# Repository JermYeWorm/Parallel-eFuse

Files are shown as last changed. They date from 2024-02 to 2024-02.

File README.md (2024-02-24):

# Parallel eFuse Development Board
Parallel eFuse Dev Board for Robotics @ Maryland. Paralleled TPS25982 15A eFuse protection board designed to protect against current transients of up to 30A from RoboSub's electronic speed controllers. Built with KiCad 7.0.
<br><br>

## Design Visuals

<br>_Fig 1. Schematic Capture_<br><br>

Parallel_eFuse_2D
<br>_Fig 2. 2D PCB Layout_<br><br>


<br>_Fig 3. 3D Model (no components)_<br><br>


<br>_Fig 4. 3D Model (mounted components)_<br><br>

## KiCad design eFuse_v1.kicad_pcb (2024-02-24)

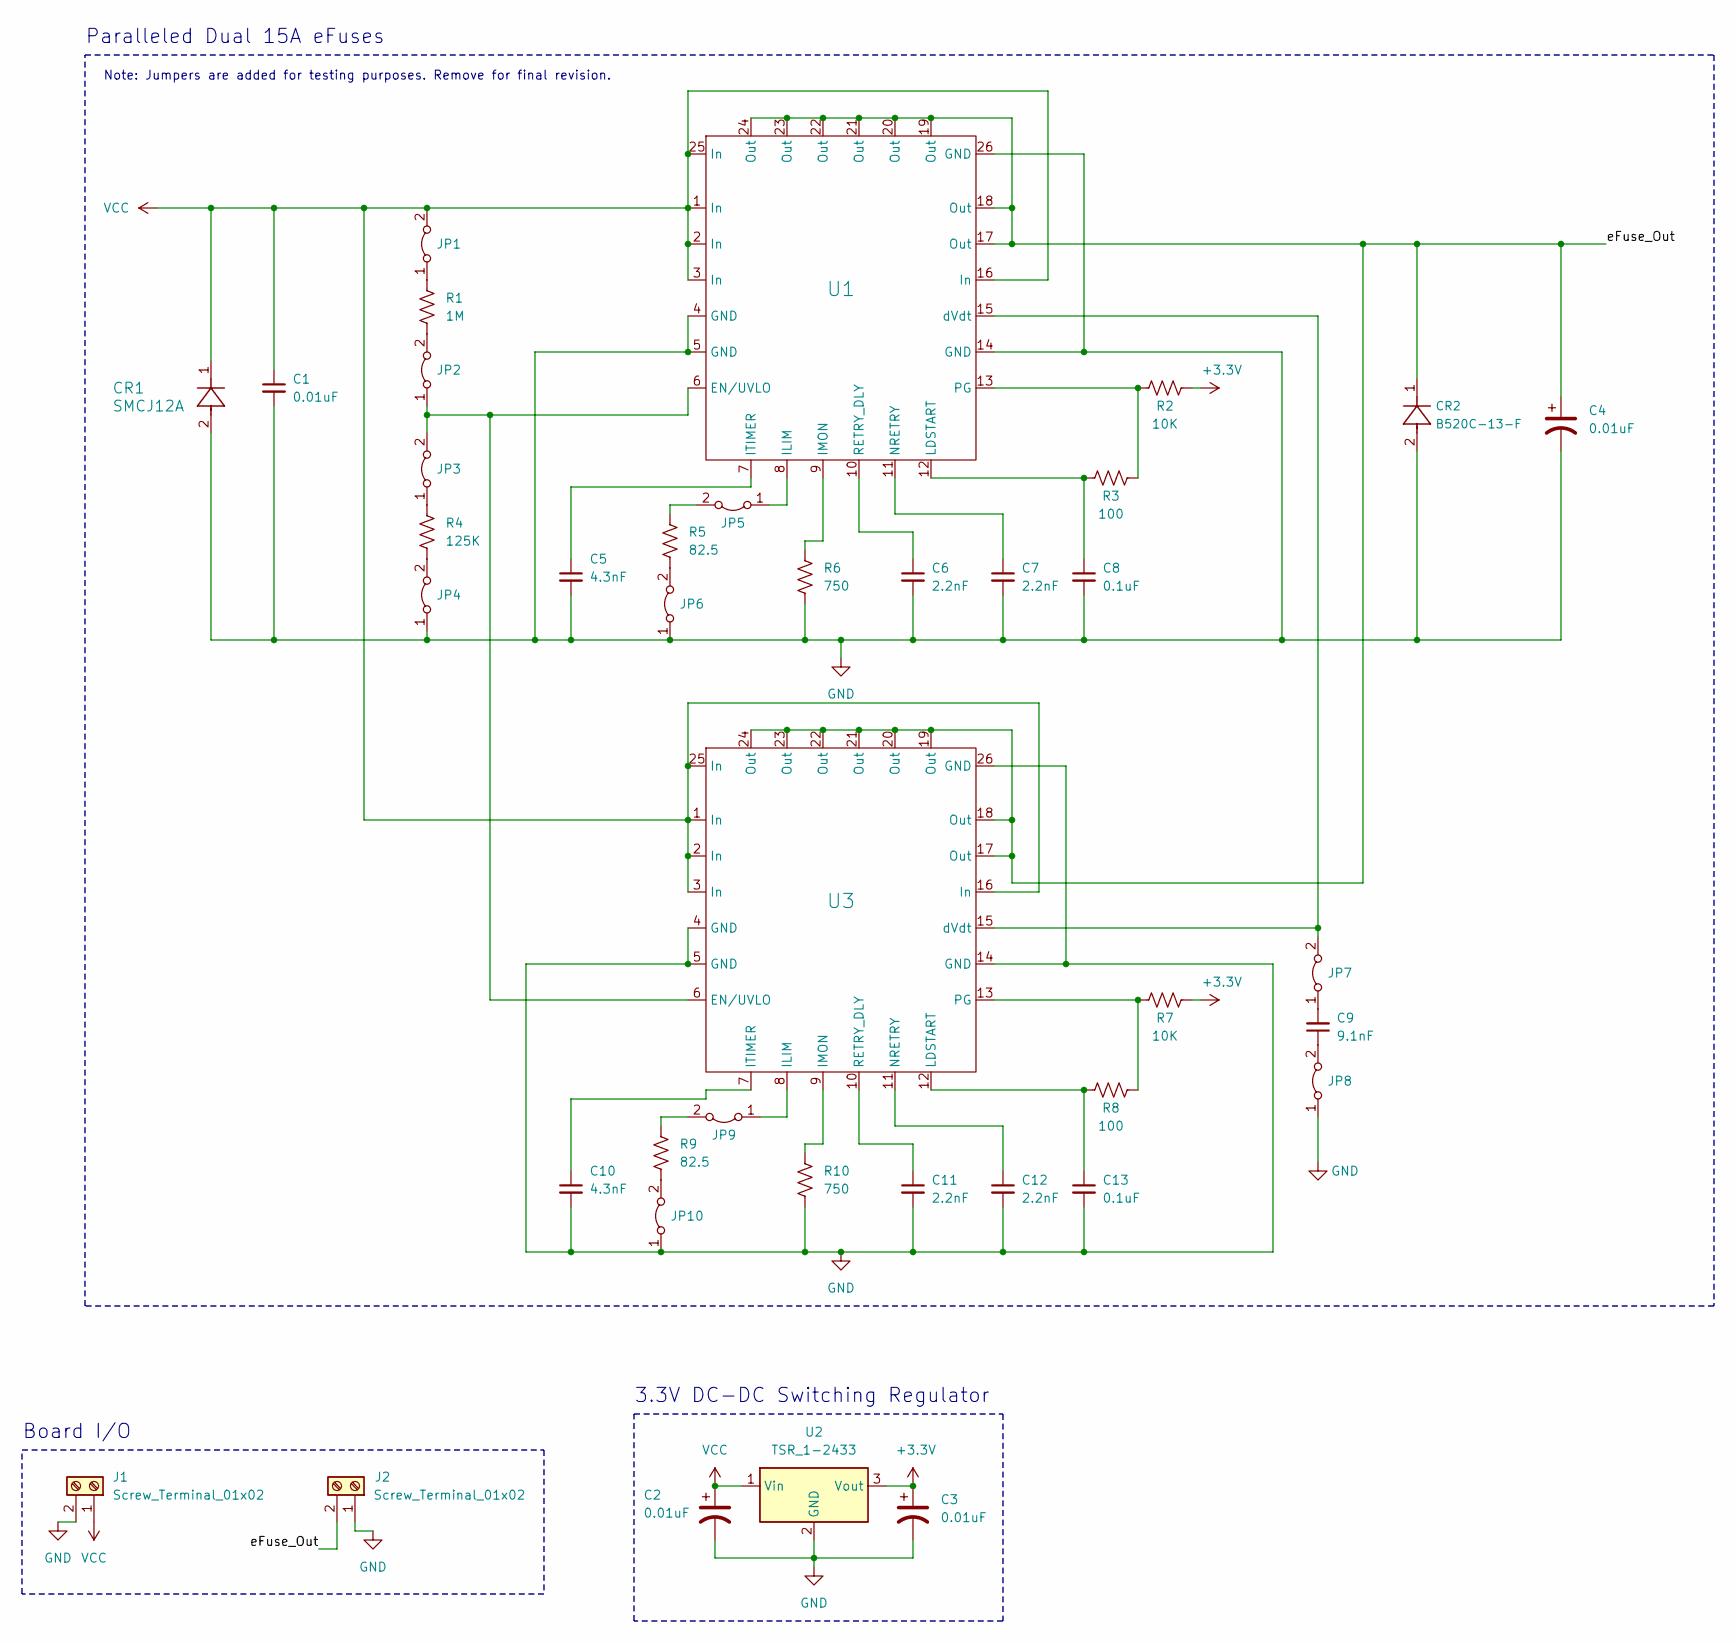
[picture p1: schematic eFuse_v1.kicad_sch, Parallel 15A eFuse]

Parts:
C1, C2, C3, C4: 0.01uF; CAP_GRM033_MUR
C5, C10: 4.3nF; CAPC340180_100N_KEM
C6, C7, C11, C12: 2.2nF; CAPC10555_55N_KEM
C8, C13: 0.1uF; CAPC0603X33N
C9: 9.1nF; CAPC2012X95N
CR1: SMCJ12A; D_SMC
CR2: B520C-13-F; D_SMC
J1, J2: Screw_Terminal_01x02; TerminalBlock_Phoenix_PT-1,5-2-5.0-H_1x02_P5.00mm_Horizontal
JP1, JP2, JP3, JP4, JP5, JP6, JP7, JP8, JP9, JP10: Jumper_2_Bridged; PinHeader_1x02_P2.54mm_Vertical
R1: 1M; RES_ERJ2RKF1004X
R2, R7: 10K; BO_CR0402
R3, R8: 100; RC0402N_YAG
R4: 125K; RESC1005X35N
R5, R9: 82.5; YAG_R0402_YAG
R6, R10: 750; RESC1005X40N
U1, U3: RGE24_2P5XP85X1P45_TEX
U2: TSR_1-2433; Converter_DCDC_TRACO_TSR-1_THT

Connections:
+3.3V: C3.1, R2.2, R7.2, U2.3 (Vout)
/eFuse_Out: C4.1, CR2.1, J2.2, U1.17 (Out), U1.18 (Out), U1.19 (Out), U1.20 (Out), U1.21 (Out), U1.22 (Out), U1.23 (Out), U1.24 (Out), U3.17 (Out), U3.18 (Out), U3.19 (Out), U3.20 (Out), U3.21 (Out), U3.22 (Out), U3.23 (Out), U3.24 (Out)
GND: C1.2, C2.2, C3.2, C4.2, C5.2, C6.2, C7.2, C8.2, C10.2, C11.2, C12.2, C13.2, CR1.2, CR2.2, J1.2, J2.1, JP4.1 (A), JP6.1 (A), JP8.1 (A), JP10.1 (A), R6.2, R10.2, U1.4 (GND), U1.5 (GND), U1.14 (GND), U1.26 (GND), U2.2 (GND), U3.4 (GND), U3.5 (GND), U3.14 (GND), U3.26 (GND)
unnamed: JP1.1 (A), R1.1
unnamed: JP2.1 (A), JP3.2 (B), U1.6 (EN/UVLO), U3.6 (EN/UVLO)
unnamed: JP2.2 (B), R1.2
unnamed: JP3.1 (A), R4.1
unnamed: JP4.2 (B), R4.2
unnamed: JP5.1 (A), U1.8 (ILIM)
unnamed: JP5.2 (B), R5.1
unnamed: JP6.2 (B), R5.2
unnamed: C9.2, JP7.1 (A)
unnamed: JP7.2 (B), U1.15 (dVdt), U3.15 (dVdt)
unnamed: C9.1, JP8.2 (B)
unnamed: JP9.1 (A), U3.8 (ILIM)
unnamed: JP9.2 (B), R9.1
unnamed: JP10.2 (B), R9.2
unnamed: R6.1, U1.9 (IMON)
unnamed: C5.1, U1.7 (ITIMER)
unnamed: C8.1, R3.1, U1.12 (LDSTART)
unnamed: C7.1, U1.11 (NRETRY)
unnamed: R2.1, R3.2, U1.13 (PG)
unnamed: C6.1, U1.10 (RETRY_DLY)
unnamed: R10.1, U3.9 (IMON)
unnamed: C10.1, U3.7 (ITIMER)
unnamed: C13.1, R8.1, U3.12 (LDSTART)
unnamed: C12.1, U3.11 (NRETRY)
unnamed: R7.1, R8.2, U3.13 (PG)
unnamed: C11.1, U3.10 (RETRY_DLY)
VCC: C1.1, C2.1, CR1.1, J1.1, JP1.2 (B), U1.1 (In), U1.2 (In), U1.3 (In), U1.16 (In), U1.25 (In), U2.1 (Vin), U3.1 (In), U3.2 (In), U3.3 (In), U3.16 (In), U3.25 (In)

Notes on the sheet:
3.3V DC-DC Switching Regulator
Note: Jumpers are added for testing purposes. Remove for final revision.
Board I/O
Paralleled Dual 15A eFuses

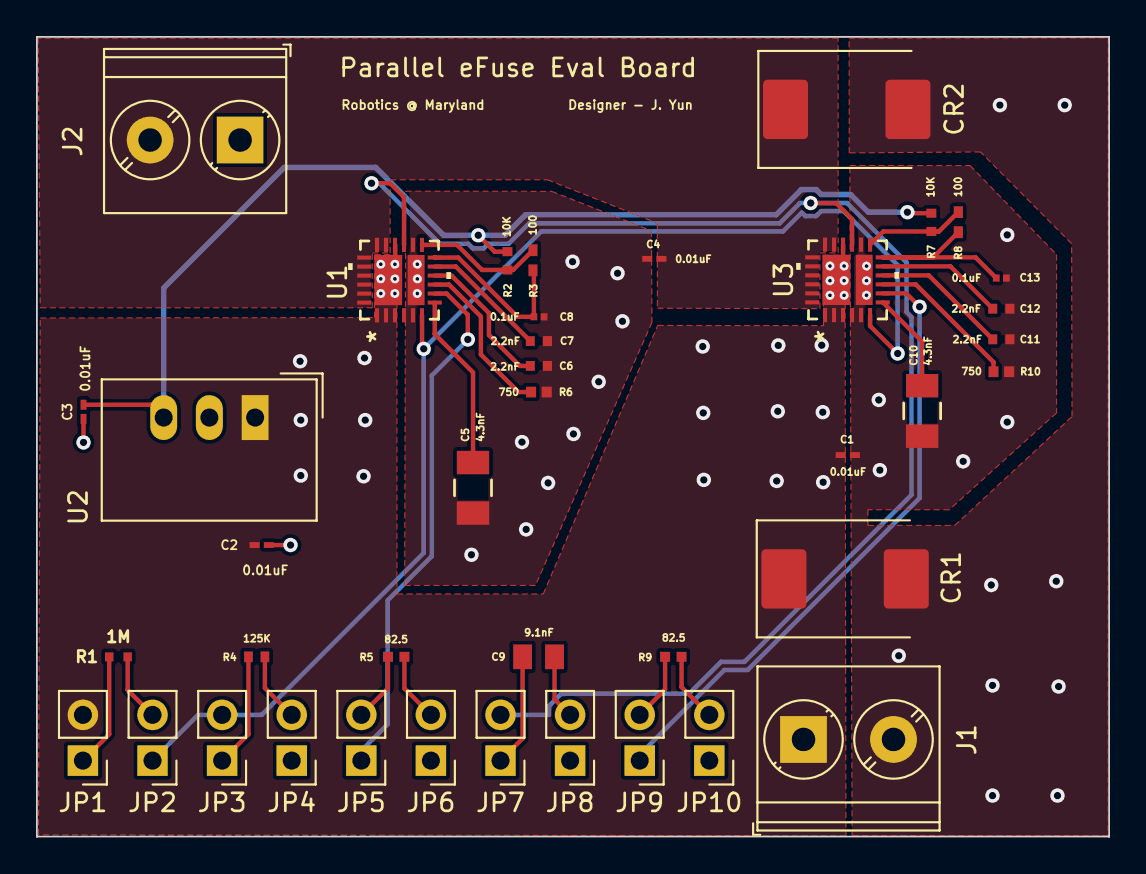
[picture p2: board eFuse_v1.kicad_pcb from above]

Board: 2 copper layers, 59.6 x 44.4 mm, 40 parts (0 on the bottom side), 30 nets.
